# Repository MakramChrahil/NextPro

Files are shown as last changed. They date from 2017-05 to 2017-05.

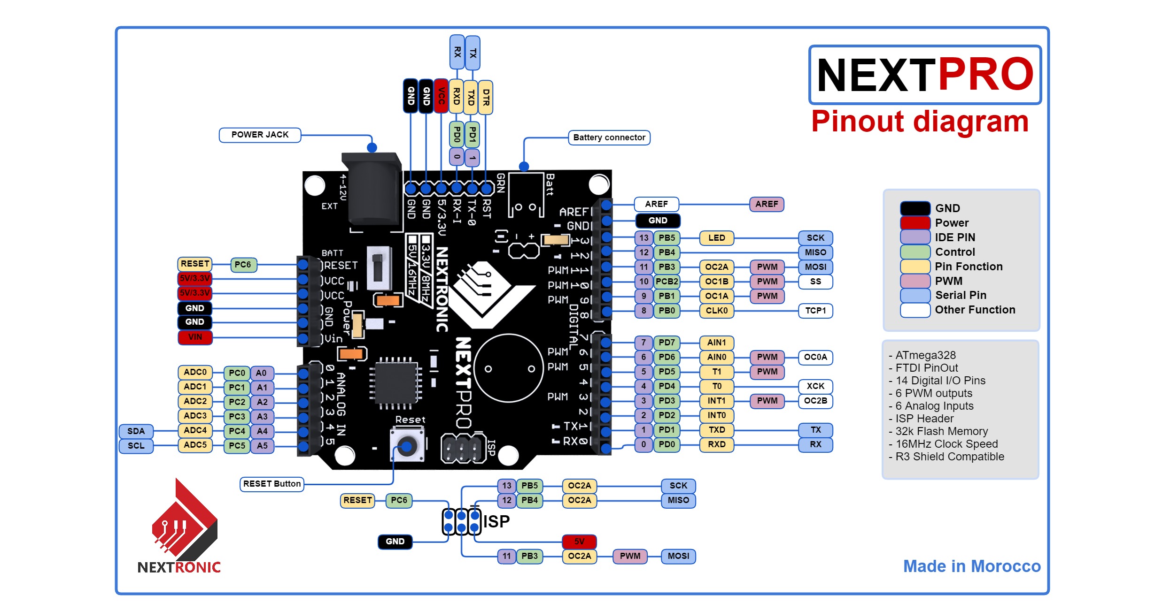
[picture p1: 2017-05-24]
Documentation/NextPro.jpg

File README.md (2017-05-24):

# Nextronic NextPro

NextPro is a minimal design approach to Arduino, it's a (5v,16Mhz)/(3.3v, 8Mhz) board based on the ATmega328P microcontroller in a small PCB that will fit easily into your next small project.
NextPro can be programmed over using an FTDI Programmer and the Arduino IDE.
NextPro is built upon the [Arduino UNO](https://www.arduino.cc/en/Main/ArduinoBoardUno) and the sparkfun [Arduino Pro](https://www.sparkfun.com/products/10915).

## Features

ATmega328 running at 16MHz/8Mhz external resonator<br />
Input voltage - 7-15V<br />
0-5V outputs<br />
14 Digital I/O Pins (6 PWM outputs)<br />
6 Analog Inputs<br />
I2C, UART and SPI<br />
32k Flash Memory<br />
5V/3.3v regulator<br />
Max 150mA output<br />
Power select switch (on/off switch)<br />
FTDI pins<br />
Buzzer<br />

<br />
<br />
Nextronic Product page:[NextPro](http://nextronic.ma/product/nextpro/).

you can by it at: [makershop.ma](http://makershop.ma/).

## Repository Contents

/Hardware - Design files (.brd, .sch)  
/Firmware - bootloader  
/Documentation - datasheet and examples

## Product Versions

NextPro_V1 first release

## License Information

The hardware is released under [Creative Commons ShareAlike 4.0 International](https://creativecommons.org/licenses/by-sa/4.0/).

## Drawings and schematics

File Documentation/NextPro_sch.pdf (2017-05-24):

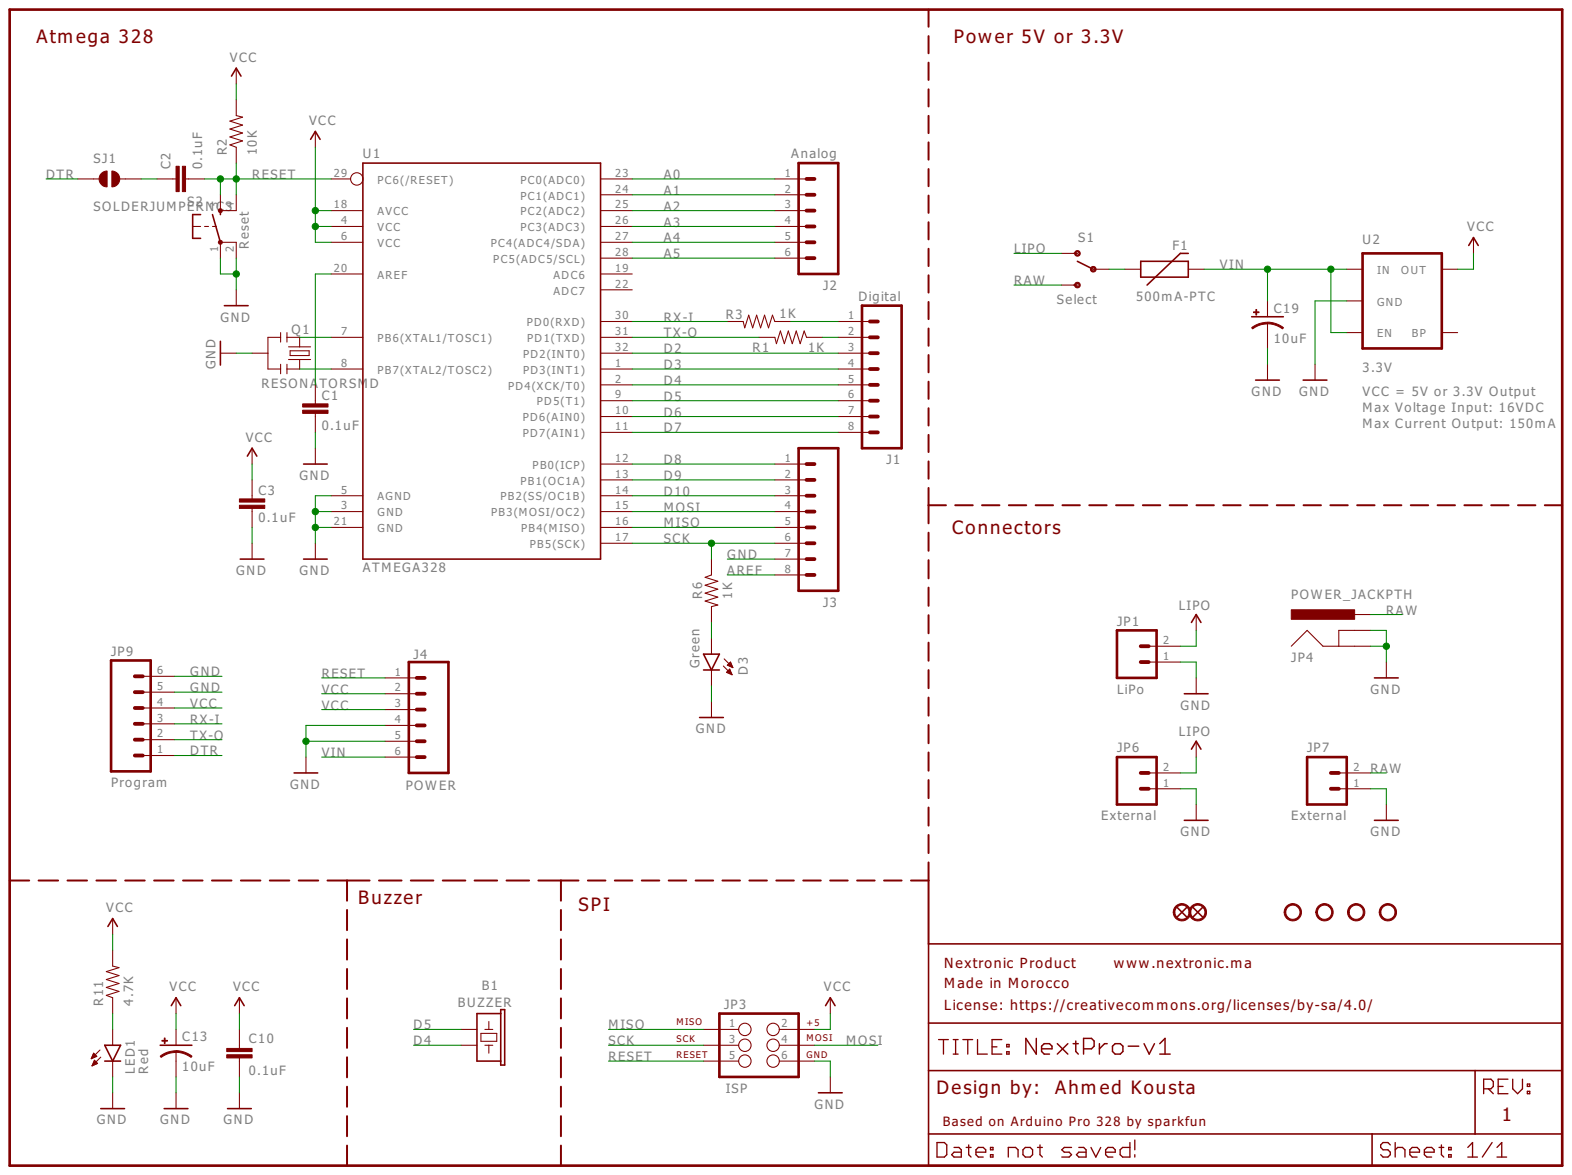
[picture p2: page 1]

VCC

VCC = 5V or 3.3V Output Max Voltage Input: 16VDC Max Current Output: 150mA

License: https://creativecommons.org/licenses/by-sa/4.0/

Based on Arduino Pro 328 by sparkfun

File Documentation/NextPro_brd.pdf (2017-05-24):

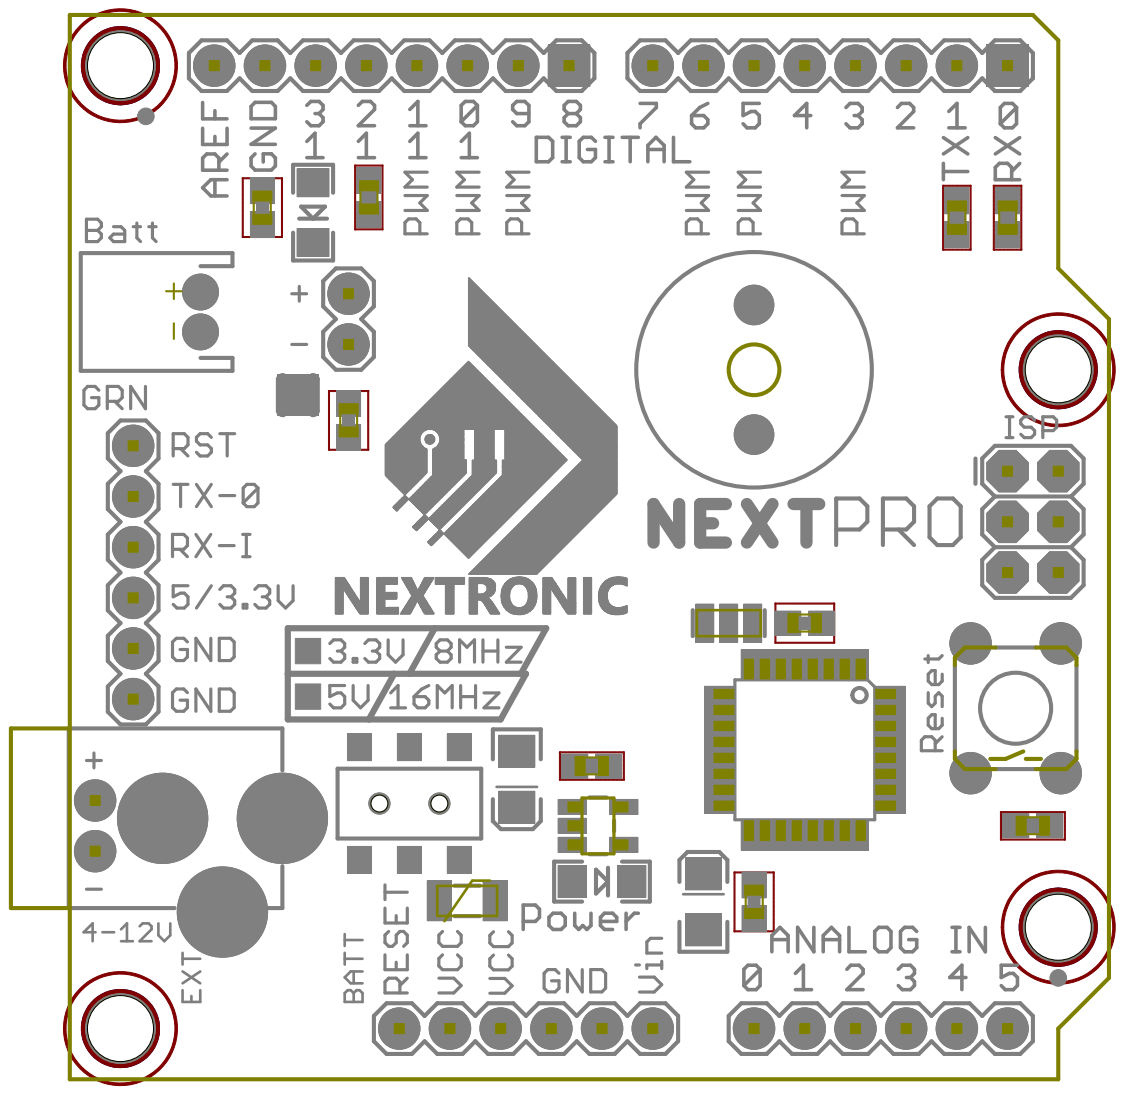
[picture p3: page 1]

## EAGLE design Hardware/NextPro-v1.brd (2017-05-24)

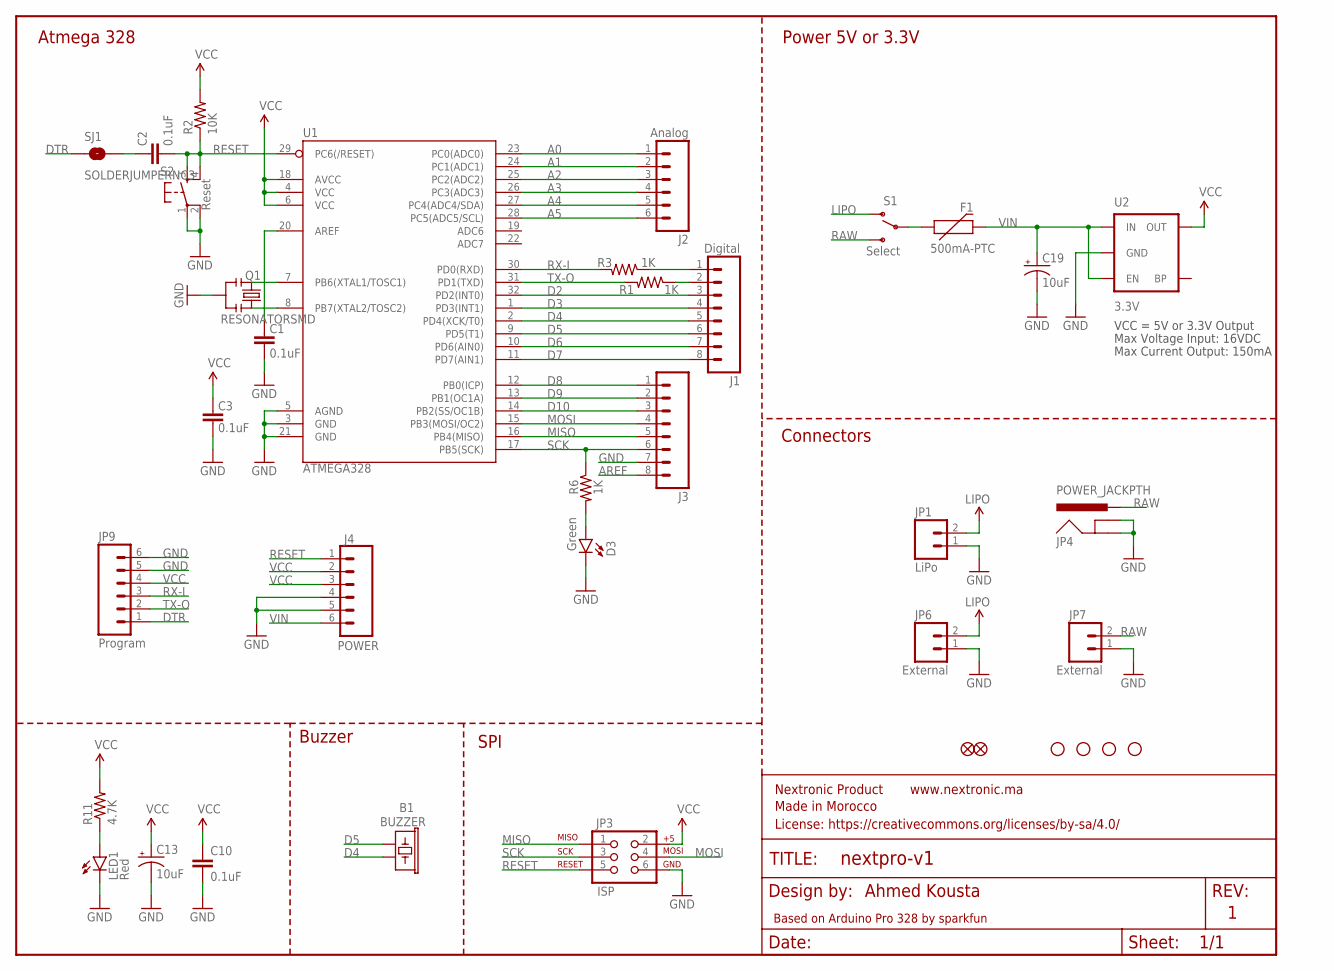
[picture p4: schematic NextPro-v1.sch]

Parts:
B1: BUZZER; BUZZER-12MM
C1, C2, C3, C10: 0.1uF; 0603-CAP
C13, C19: 10uF; EIA3216
D3: Green; LED-1206
F1: 500mA-PTC; PTC-1206
FRAME1: FRAME-LETTER; CREATIVE_COMMONS
J1: Digital; 1X08
J2: Analog; 1X06
J3: M081X08; 1X08
J4: POWER; 1X06
JP1: LiPo; JST-2-PTH
JP2, JP5: FIDUCIAL1X2.5; FIDUCIAL-1X2.5
JP3: ISP; 2X3
JP4: POWER_JACKPTH; POWER_JACK_PTH
JP6: External; 1X02
JP7: External; 1X02_NO_SILK
JP9: Program; 1X06
LED1: Red; LED-1206
Q1: RESONATORSMD; RESONATOR-SMD
R1, R3, R6: 1K; 0603-RES
R2: 10K; 0603-RES
R11: 4.7K; 0603-RES
S1: Select; AYZ0202
S2: Reset; TACTILE-PTH
SJ1: SOLDERJUMPERNC3; SJ_2S-NOTRACE
U1: ATMEGA328; TQFP32-08
U2: 3.3V; SOT23-5
U$1, U$3, U$9, U$10: STAND-OFF

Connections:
A0: J2.1, U1.23 (PC0(ADC0))
A1: J2.2, U1.24 (PC1(ADC1))
A2: J2.3, U1.25 (PC2(ADC2))
A3: J2.4, U1.26 (PC3(ADC3))
A4: J2.5, U1.27 (PC4(ADC4/SDA))
A5: J2.6, U1.28 (PC5(ADC5/SCL))
AREF: C1.2, J3.8, U1.20 (AREF)
D2: J1.3, U1.32 (PD2(INT0))
D3: J1.4, U1.1 (PD3(INT1))
D4: B1.- (2), J1.5, U1.2 (PD4(XCK/T0))
D5: B1.+ (1), J1.6, U1.9 (PD5(T1))
D6: J1.7, U1.10 (PD6(AIN0))
D7: J1.8, U1.11 (PD7(AIN1))
D8: J3.1, U1.12 (PB0(ICP))
D9: J3.2, U1.13 (PB1(OC1A))
D10: J3.3, U1.14 (PB2(SS/OC1B))
DTR: JP9.1, SJ1.1
GND: C1.1, C3.1, C10.2, C13.C (-), C19.C (-), D3.C, J3.7, J4.4, J4.5, JP1.1, JP3.6, JP4.GND, JP4.GNDBREAK, JP6.1, JP7.1, JP9.5, JP9.6, LED1.C, Q1.2, S2.1, S2.2, U1.3 (GND), U1.5 (AGND), U1.21 (GND), U2.2 (GND)
LIPO: JP1.2, JP6.2, S1.1 (O)
MISO: J3.5, JP3.1, U1.16 (PB4(MISO))
MOSI: J3.4, JP3.4, U1.15 (PB3(MOSI/OC2))
unnamed: C2.1, SJ1.2
unnamed: Q1.1, U1.8 (PB7(XTAL2/TOSC2))
unnamed: Q1.3, U1.7 (PB6(XTAL1/TOSC1))
unnamed: D3.A, R6.2
unnamed: F1.1, S1.2
unnamed: LED1.A, R11.1
RAW: JP4.PWR, JP7.2, S1.3 (S)
RESET: C2.2, J4.1, JP3.5, R2.1, S2.3, S2.4, U1.29 (PC6(/RESET))
RX-I: JP9.3, R3.2, U1.30 (PD0(RXD))
RX-IP: J1.2, R1.1
SCK: J3.6, JP3.3, R6.1, U1.17 (PB5(SCK))
TX-O: JP9.2, R1.2, U1.31 (PD1(TXD))
TX-OP: J1.1, R3.1
VCC: C3.2, C10.1, C13.A (+), J4.2, J4.3, JP3.2, JP9.4, R2.2, R11.2, U1.4 (VCC), U1.6 (VCC), U1.18 (AVCC), U2.5 (OUT)
VIN: C19.A (+), F1.2, J4.6, U2.1 (IN), U2.3 (EN)

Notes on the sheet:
VCC = 5V or 3.3V Output
Max Voltage Input: 16VDC
Max Current Output: 150mA
Ahmed Kousta
Based on Arduino Pro 328 by sparkfun
Atmega 328
Power 5V or 3.3V
Connectors
Buzzer
SPI

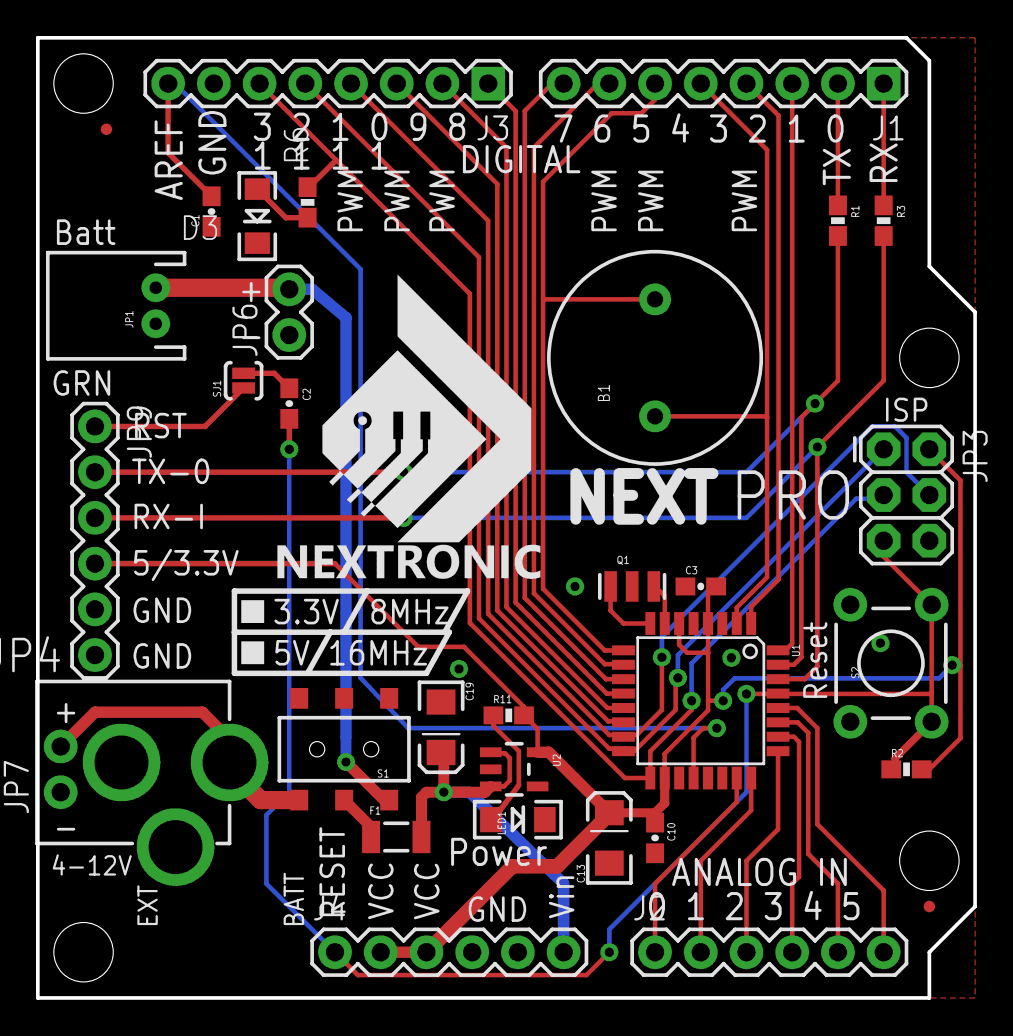
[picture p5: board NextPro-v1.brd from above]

Board: 2 copper layers, 52.1 x 53.3 mm, 38 parts (0 on the bottom side), 36 nets.

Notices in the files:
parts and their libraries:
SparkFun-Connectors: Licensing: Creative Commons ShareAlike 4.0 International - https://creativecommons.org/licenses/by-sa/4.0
